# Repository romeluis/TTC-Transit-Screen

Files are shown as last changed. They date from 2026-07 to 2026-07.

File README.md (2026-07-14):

# TTC Transit Screen

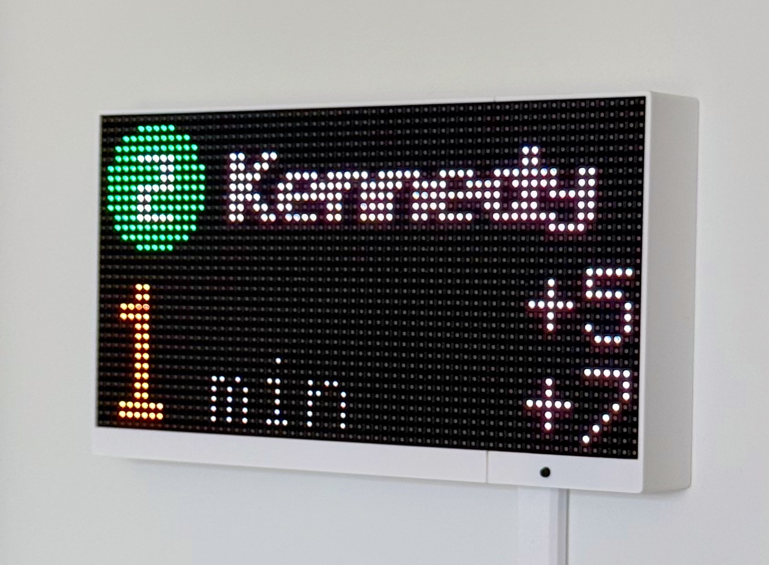
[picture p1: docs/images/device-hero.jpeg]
A wall-mounted TTC Transit Screen showing Line 2 arrivals


An open-source, Wi-Fi-connected TTC arrival display built around an ESP32-S3 and a 64×32 P4 HUB75 RGB LED panel. It shows the next arrivals for up to eight subway, streetcar, or bus stops, includes line-alert indicators, and is configured from a phone-friendly local web app.

This is an independent community project. It is not affiliated with, endorsed by, or supported by the Toronto Transit Commission. Transit data can be delayed, incomplete, or unavailable; do not rely on this display for safety-critical travel decisions.

## What it does

- Shows three upcoming arrivals on a bright 64×32 RGB matrix.
- Supports subway platforms through TTC NTAS and surface routes through the public NextBus/UMO feed.
- Shows a warning triangle when TTC's live-alert feed reports an active line issue.
- Stores up to eight pages and cycles through them with an optional button.
- Hosts a captive setup portal and a responsive local configuration page.
- Sleeps the panel and pauses feed polling on a configurable overnight schedule.
- Supports local over-the-air firmware updates.
- Requires no cloud account, application server, or hardcoded stop selection.

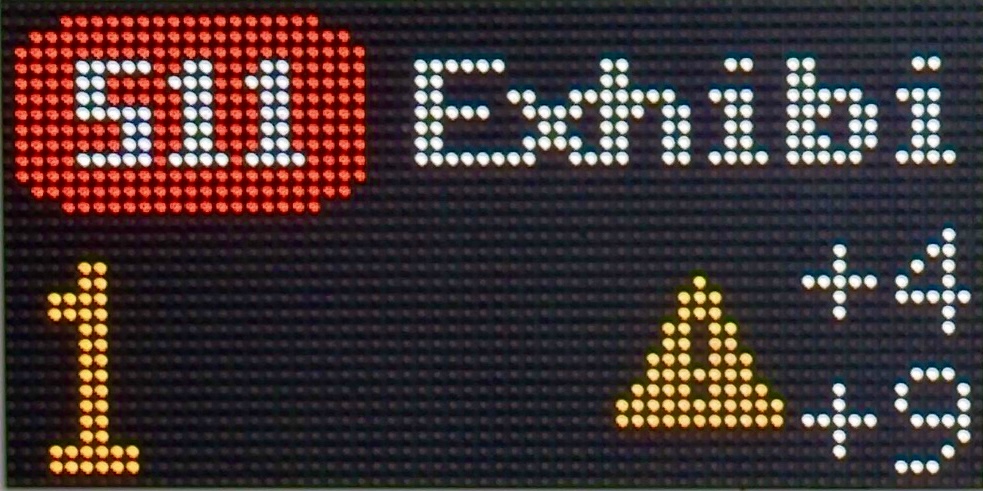
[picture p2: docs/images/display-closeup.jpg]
Close view of a surface-route arrival page


*The 64×32 layout showing a surface route, destination, alert state, and arrival minutes.*

## Supported boards

| PlatformIO environment | Memory | Status |
| --- | --- | --- |
| `esp32-s3-n16r8` | 16 MB flash, 8 MB octal PSRAM (`qio_opi`) | Default; tested on hardware |
| `esp32-s3-n8r2` | 8 MB flash, 2 MB quad PSRAM (`qio_qspi`) | Clean-build tested; not yet tested on hardware |

Both targets use the same 44-pin ESP32-S3 board layout, HUB75 wiring, firmware, and web app. Clone pin labels and power paths can vary, so compare your board with the wiring table before applying power.

## Bill of materials

| Qty | Item | Notes |
| ---: | --- | --- |
| 1 | [ESP32-S3 N16R8/N8R2 development board](https://www.aliexpress.com/item/1005006418608267.html) | N16R8 is the tested and default choice |
| 1 | [P4 indoor 64×32, 256×128 mm, 1/16-scan HUB75 panel](https://www.aliexpress.com/item/1005007439197222.html) | This geometry and scan rate are compile-time constants |
| 1 | Quality regulated 5 V / 3 A USB-C supply | Used by the tested USB-powered topology below |
| 1 | Low-resistance USB-C cable rated for at least 3 A | A marginal cable is a common source of resets and display corruption |
| 1 | HUB75 ribbon cable | Often included with the panel |
| 1 set | Female-to-female jumper wires or a purpose-built wiring harness | Keep signal wiring short and secure |
| 6 | M3×6 machine screws | Engage the panel's threaded inserts through the enclosure |
| 1 | [Momentary tact switch](https://www.aliexpress.com/item/1005007078720195.html) | Optional; the linked assortment is simply the kit used during development |
| 1 | Printed enclosure | Fusion archive and two printable STLs are included under [`hardware/enclosure`](hardware/enclosure/) |

A direct 5 V / 5 A supply, suitable wiring, and a fused distribution method are recommended as a fallback if the tested USB topology is unstable with your particular board or display.

## Power: read before wiring

The tested unit is powered through the ESP32's USB-C connector. The board's `5Vin` pin then supplies 5 V to the panel. At the fixed brightness value of 96, the measured normal workload was under 1 A because most pixels are black. That observation is not a worst-case rating: startup current, test patterns, different panels, USB cables, and board clones can draw more or expose a weak power path.

- Use a reputable regulated 5 V / 3 A USB-C supply and a short, low-resistance cable.
- Check the ESP32 board, connector, wiring, and panel for excess heat during initial testing.
- Watch for brownouts, spontaneous resets, flicker, or corrupted pixels.
- Do not feed external 5 V into `5Vin` while USB 5 V is also connected. Back-feeding can damage the board, computer, or supply.
- Never power the panel from the ESP32's 3.3 V pin or through its voltage regulator.

If USB power is not stable, use a regulated 5 V / 5 A supply split directly to the panel power input and the ESP32 `5Vin`, with all grounds common. Disconnect that external 5 V before connecting an ordinary powered USB cable for flashing.

## HUB75 wiring

The firmware uses one fixed pin map. The table follows the two columns of a standard HUB75 input connector; confirm the `IN` connector and key orientation on your panel.

| HUB75 signal | ESP32-S3 GPIO | HUB75 signal | ESP32-S3 GPIO |
| --- | ---: | --- | ---: |
| R1 | 4 | G1 | 1 |
| B1 | 5 | G2 | 2 |
| R2 | 6 | B (row address) | 42 |
| B2 | 7 | D | 41 |
| A | 15 | LAT / STB | 40 |
| C | 16 | E | GND |
| CLK | 17 | GND | GND |
| OE | 18 | GND | GND |

Connect every panel ground on the HUB75 header to ESP32 ground. Connect panel power `VCC` to the board's `5Vin` only when using the tested USB topology, and panel power ground to the same common ground. The 32-row, 1/16-scan panel does not use address line E, so E is tied to ground.

For the optional page/reset button, connect the momentary switch between GPIO21 and GPIO47. GPIO21 is the active-low input; GPIO47 is driven LOW as a virtual ground because of the compact harness layout. This virtual ground is only for the switch's tiny current—never connect a display, LED, or other load to GPIO47.

Without the button, the device still provisions, fetches data, sleeps on schedule, and can be managed through the web app. Only the first configured page is shown, and physical factory reset is unavailable.

## Prebuilt firmware

The [latest GitHub release](https://github.com/romeluis/TTC-Transit-Screen/releases/latest) includes ready-to-flash binaries for both supported memory variants. Choose the file whose board name exactly matches your ESP32-S3:

| File suffix | Use |
| --- | --- |
| `esp32-s3-n16r8-factory.bin` | First USB installation on the tested 16 MB flash / 8 MB PSRAM board |
| `esp32-s3-n16r8-ota.bin` | Firmware-tab update for the tested N16R8 board |
| `esp32-s3-n8r2-factory.bin` | First USB installation on the compile-supported 8 MB flash / 2 MB PSRAM board |
| `esp32-s3-n8r2-ota.bin` | Firmware-tab update for the compile-supported N8R2 board |

The `factory` images contain the bootloader, partition table, and application and are written at address `0x0`. Install [esptool](https://docs.espressif.com/projects/esptool/en/latest/esp32s3/installation.html), connect the board over USB, then run:

```sh
python -m esptool --chip esp32s3 --port /dev/your-port write-flash 0x0 ttc-transit-screen-v1.1.0-esp32-s3-n16r8-factory.bin
```

Replace the port and filename for your board. If the board does not enter download mode automatically, hold BOOT, tap RESET, start the command, then release BOOT. The release also includes `SHA256SUMS.txt` so downloads can be verified before flashing.

## Build and flash

Install [PlatformIO Core](https://docs.platformio.org/en/latest/core/installation/index.html), clone this repository, and run the commands from its root.

```sh
# Default, hardware-tested N16R8 target
pio run -e esp32-s3-n16r8
pio run -e esp32-s3-n16r8 -t upload

# Compile-supported N8R2 target
pio run -e esp32-s3-n8r2
pio run -e esp32-s3-n8r2 -t upload

# Optional serial diagnostics
pio device monitor -b 115200
```

The pre-build script compresses `web/index.html` and the station catalog into `include/web_page.h`; the generated header is intentionally ignored by Git. Use the native USB connector labelled `USB` when the board exposes both native USB and UART connectors. If automatic upload does not start, hold BOOT, tap RESET, begin the upload, then release BOOT.

### Fixed build-time settings

This project intentionally has no runtime brightness control. The tested value is `PANEL_BRIGHTNESS = 96` in [`src/config.h`](src/config.h). Change it at source level only, then rebuild and re-check current draw and temperature.

The following hardcoded values are intentional and collected here so they are easy to review before a build:

| Setting | Compiled value |
| --- | --- |
| Panel | 64×32 pixels, 1/16 scan; shared pins listed above |
| Brightness | 96 of 255 |
| Maximum pages | 8 |
| Arrival polling | 25 seconds per feed, staggered by 3 seconds |
| Alert polling | 120 seconds |
| Stale-data threshold | 90 seconds |
| HTTP timeout | 10 seconds |
| Wi-Fi connection timeout | 45 seconds |
| Reconnect backoff | 5–60 seconds |
| Portal fallback after lost Wi-Fi | 5 minutes |
| Stored-network retry while in portal | 2 minutes |
| Physical factory-reset hold | 10 seconds |
| Setup network | Open SSID `TTC-Setup` |
| Local hostname | `ttc` / `http://ttc.local` |
| Timezone | `America/Toronto` POSIX rules; NTP via `pool.ntp.org` and `time.google.com` |
| Default sleep schedule | 9 PM–6 AM local time; 30-second button wake |
| Subway feed | `https://ntas.ttc.ca/api/ntas/get-next-train-time/` |
| Surface feed | `https://retro.umoiq.com/service/publicJSONFeed` with agency `ttc` |
| Alert feed | `https://alerts.ttc.ca/api/alerts/live-alerts` |

Stops and the active sleep schedule are not hardcoded; they are stored in the device's NVS after configuration.

## First-time setup

1. Power the assembled device and wait for the `WiFi Setup` screen.
2. Join the open Wi-Fi network `TTC-Setup` from a phone or computer.
3. Open the captive-portal prompt. If it does not appear, browse to the IP shown on the panel.
4. Open the **WiFi** tab, scan or type the network name, enter its password, and choose **Save & connect**.
5. After restart, browse to [http://ttc.local](http://ttc.local). If mDNS is unavailable on your network, use the IP shown in the web app or serial log.
6. In **Stops**, add up to eight pages in the order you want them displayed, then choose **Save to device**.
7. In **Display**, keep the default overnight schedule or set your preferred local hours and button wake time.

Subway stops come from the embedded station/platform catalog. Streetcar and bus selectors are loaded through the ESP32's NextBus proxy and therefore require internet access. A fresh device contains no default stops or personal location data.

## Web app

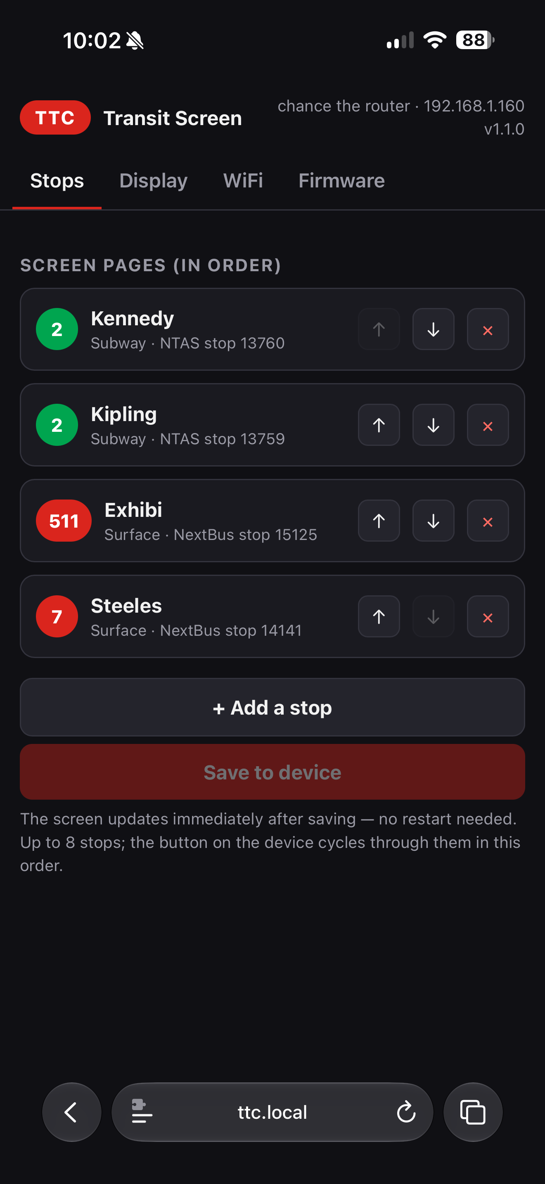
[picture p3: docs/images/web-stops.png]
Mobile Stops tab listing configured transit pages


*The Stops tab adds, removes, reorders, and saves up to eight display pages.*

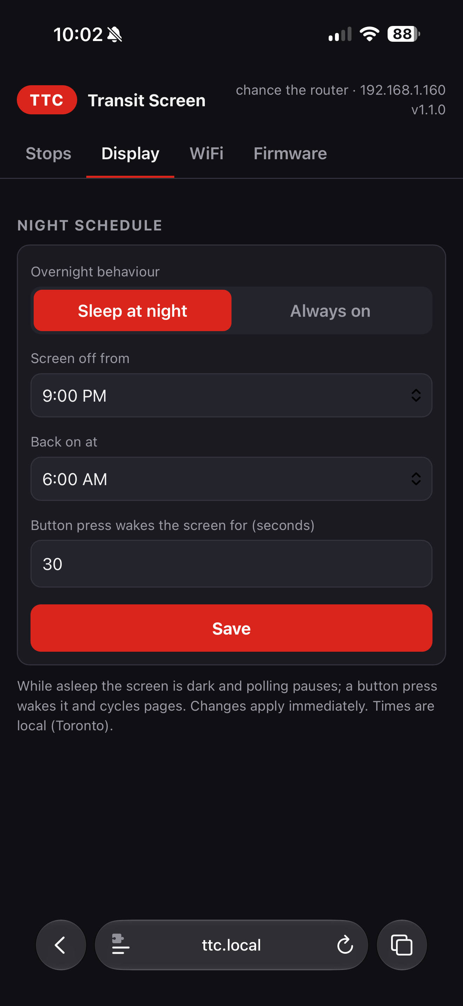
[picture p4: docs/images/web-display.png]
Mobile Display tab with overnight schedule settings


*The Display tab configures the panel's overnight sleep window and button wake time. It does not include brightness control.*

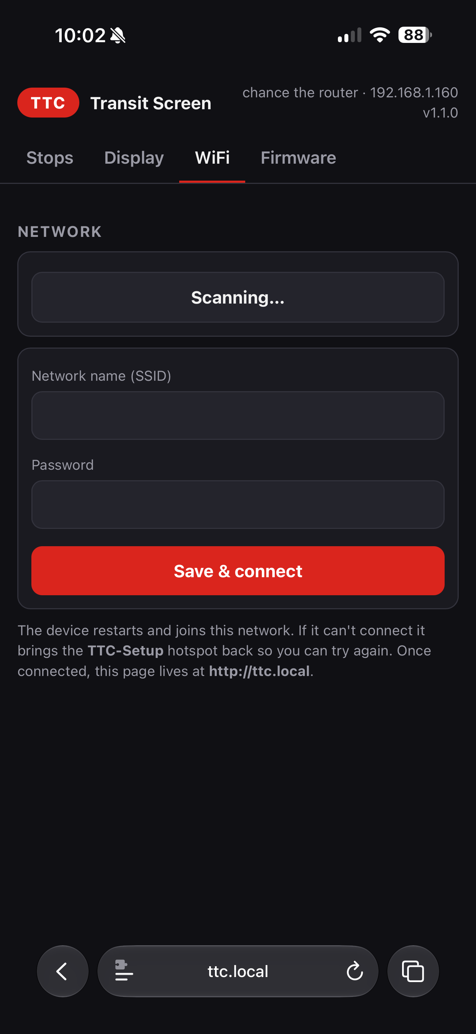
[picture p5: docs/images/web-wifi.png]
Mobile Wi-Fi tab with blank credential fields


*The Wi-Fi tab scans for a network, saves credentials, and reconnects the device.*

## Daily operation

- A short button press cycles pages in the configured order.
- During the sleep window, the first press wakes the panel without changing page. Further presses while awake cycle pages and extend the wake timer.
- Holding the button for 10 seconds after boot wipes Wi-Fi credentials, stops, and screen settings, then restarts the setup portal.
- If Wi-Fi drops, the firmware retries with exponential backoff. After a prolonged outage it reopens the setup portal while continuing to retry stored credentials.
- Feed polling pauses while the screen is asleep and resumes immediately on wake.

## Local firmware update

Build the firmware for the exact memory variant installed. In the web app's **Firmware** tab, upload:

- `.pio/build/esp32-s3-n16r8/firmware.bin`, or
- `.pio/build/esp32-s3-n8r2/firmware.bin`.

The ESP32 writes to the inactive OTA slot and restarts only after a successful upload. The firmware page is unauthenticated; read the security section before enabling this device on a shared network.

## Enclosure

The enclosure source and both printable halves are in [`hardware/enclosure`](hardware/enclosure/). The assembled STL bounds are approximately **260.5 × 142.5 × 36 mm**. The fit was tested in PLA. A reasonable starting profile is 0.2 mm layers, three walls, and 20% infill, with each half laid flat on its broad back face.

The enclosure has six panel mounting holes for M3×6 screws. It is provided as-is by a hobbyist designer: printer calibration, panel revisions, cable strain relief, and tolerances vary. Test-fit before final assembly, do not overtighten the panel inserts, and contributions improving the design are welcome.

## Architecture and repository layout

| Path | Purpose |
| --- | --- |
| `src/main.cpp` | Network state machine, scheduling, button handling, sleep/wake behavior |
| `src/transit_data.cpp` | TTC/NextBus fetching and JSON parsing |
| `src/display.cpp` | Shared 64×32 HUB75 rendering |
| `src/settings.cpp` | NVS-backed stops, Wi-Fi credentials, and screen schedule |
| `src/webconfig.cpp` | Captive portal, local HTTP API, feed proxy, reboot, and OTA |
| `web/` | Embedded responsive configuration UI and public station catalog |
| `tools/build_web.py` | Deterministic web-asset compression before each firmware build |
| `hardware/enclosure/` | Fusion archive, printable STLs, and print notes |

The device connects directly to public transit feeds, parses only the fields it needs, stores runtime configuration in NVS, renders the active page to the HUB75 panel, and serves the web app over the local network. No companion service is required.

### Data sources

- TTC NTAS next-train endpoint for subway platform estimates
- NextBus/UMO public JSON feed for bus and streetcar predictions
- TTC live-alert endpoint for line-level disruption indicators
- TTC GTFS-derived platform codes in the embedded station catalog

These are public endpoints, not stable contracts. Upstream schema, availability, stop codes, or access policies may change without notice.

## Security model

> **Trusted LAN only.** This firmware is designed for a private network, not an untrusted, guest, school, workplace, or internet-exposed network.

- The `TTC-Setup` access point is open and its captive portal has no authentication.
- Wi-Fi credentials are submitted over plaintext local HTTP and stored unencrypted in ESP32 NVS.
- The status endpoint and page expose the connected SSID and local IP address.
- Stop/schedule/Wi-Fi configuration, reboot, and OTA endpoints are unauthenticated.
- HTTPS certificate validation is disabled for the public transit feeds, so transit responses are not protected against an active network attacker.

Do not port-forward the device, expose it through a public reverse proxy, or place it on a network where untrusted clients can reach it. A separate trusted IoT VLAN is a good deployment choice. See [`SECURITY.md`](SECURITY.md) for the full disclosure and reporting guidance.

## Troubleshooting

| Symptom | Checks |
| --- | --- |
| Reboots, flicker, or random pixels | Use a better 5 V supply/cable, shorten power leads, tie all grounds together, and try the direct 5 V / 5 A split topology |
| Panel is blank | Confirm HUB75 `IN` orientation, OE/LAT/CLK wiring, common ground, panel power, and the 1/16-scan 64×32 panel type |
| Colours or rows are wrong | Recheck R/G/B and A/B/C/D wires; confirm E is grounded and that your panel is not a different scan geometry |
| `TTC-Setup` does not appear | Hold the optional button for 10 seconds after boot, or erase flash over USB and reflash |
| `ttc.local` does not resolve | Use the device IP from serial output or your router's client list; some networks do not pass mDNS |
| Streetcar/bus picker fails | Confirm internet access; the browser relies on the ESP32 proxy because the upstream feed has no browser CORS support |
| No or stale arrivals | Verify stop codes, upstream service status, Wi-Fi signal, and serial diagnostics; predictions are controlled by the external feeds |
| OTA rejects a file | Rebuild for the exact N16R8/N8R2 target and upload that environment's `firmware.bin` |

## Release verification

CI clean-builds both memory variants. Before distributing hardware, repeat the N16R8 smoke test: cold boot/display initialization, first-time provisioning, stop fetching, disconnect/reconnect, scheduled sleep and button wake, page cycling, 10-second factory reset, and OTA update. Treat N8R2 as compile-tested until the same checklist has been completed on physical N8R2 hardware.

## License

This repository—including firmware, web assets, documentation, photos, and enclosure files—is released under the [MIT License](LICENSE).

Created and maintained by [@romeluis](https://github.com/romeluis).

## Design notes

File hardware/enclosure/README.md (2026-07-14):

# P4 panel enclosure

This directory contains the editable Fusion archive and two printable halves for the 256×128 mm P4 HUB75 panel used by TTC Transit Screen.

- `p4-screen-case.f3d` — editable Fusion design archive
- `left-body.stl` — left enclosure half
- `right-body.stl` — right enclosure half

The combined STL bounds are approximately **260.5 × 142.5 × 36 mm**. The enclosure was test-printed in PLA. As a starting point, place each half flat on its broad back face and use:

- 0.2 mm layer height
- three walls/perimeters
- 20% infill
- supports only where your slicer's preview shows they are necessary

Use six M3×6 machine screws through the enclosure holes into the panel's threaded inserts. Start every screw loosely, align the panel, then tighten evenly. Do not overtighten the inserts.

This is a hobbyist design supplied as-is. Panel frames, connectors, print shrinkage, and printer calibration vary. Check cable clearance and test-fit all parts before final assembly. Improvements to tolerances, joining features, ventilation, or strain relief are welcome.

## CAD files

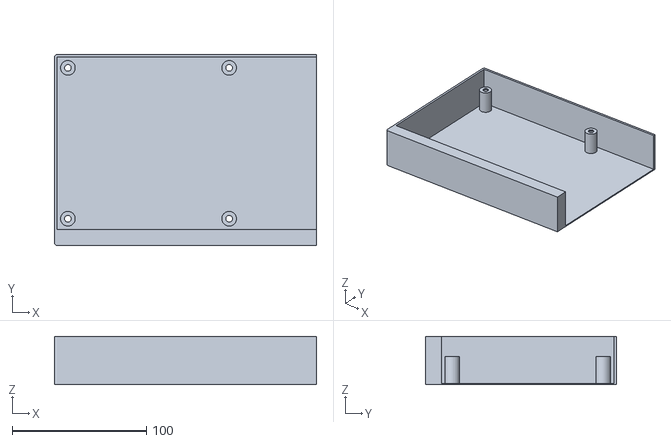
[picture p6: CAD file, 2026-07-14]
hardware/enclosure/left-body.stl
195.4 x 142.5 x 36.0

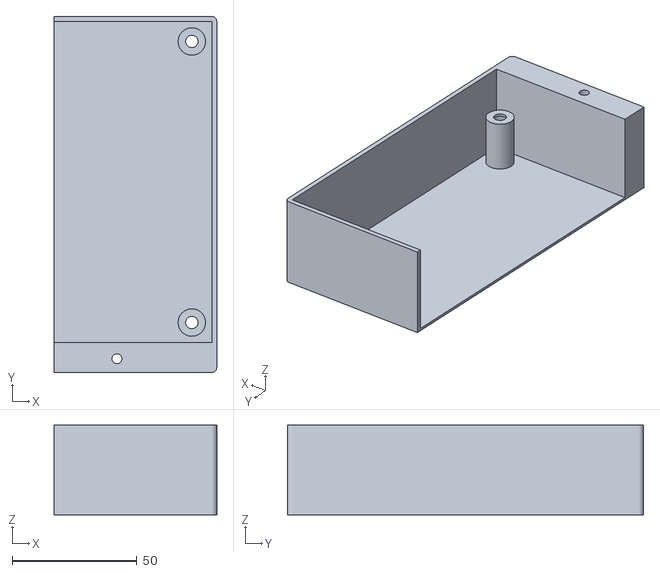
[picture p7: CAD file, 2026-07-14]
hardware/enclosure/right-body.stl
65.1 x 142.5 x 36.0

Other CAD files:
hardware/enclosure/p4-screen-case.f3d

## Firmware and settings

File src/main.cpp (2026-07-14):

// TTC Transit Screen — fetch-first firmware.
//
// Polls a prediction feed per configured stop (gStops, NVS-backed via the
// web-config UI: subway via NTAS, streetcar/bus via NextBus) and prints
// arrivals to serial. Rendering targets the HUB75 matrix with ENABLE_DISPLAY;
// without it the firmware remains usable for serial diagnostics.
//
// Networking is a small state machine: stored credentials are tried first
// (StaConnecting); if none exist or they keep failing, the device hosts an
// open setup AP with a captive portal (Portal) where WiFi and stops can be
// configured. The web server runs in every mode.

#include <Arduino.h>
#include <ESPmDNS.h>
#include <WiFi.h>
#include <esp_system.h> // esp_reset_reason
#include <time.h>

#include "config.h"
#include "display.h"
#include "settings.h"
#include "transit_data.h"
#include "webconfig.h"

static TransitState state;
static AlertState alerts;
static uint32_t feedDueAtMs[MAX_STOPS];
static uint32_t alertsDueAtMs = 0; // set in scheduleFetches (count is runtime)

enum class NetMode : uint8_t { StaConnecting, StaConnected, Portal };
static NetMode netMode = NetMode::Portal;
static String staSsid, staPass;               // from NVS
static uint32_t staDeadlineMs = 0;            // StaConnecting -> portal at
static uint32_t staRetryAtMs = 0;             // next reconnect attempt
static uint32_t staBackoffMs = WIFI_RETRY_BASE_MS;
static uint32_t staLostSinceMs = 0;           // 0 = link is up
static uint32_t statusScreenAtMs = 0;         // boot/setup screen refresh
static bool timeConfigured = false;

static FetchStatus fetchStop(const StopConfig &stop, Departures &dep) {
  return stop.kind == RouteKind::Subway
             ? fetchSubway(stop.stopId, dep)
             : fetchNextBus(stop.route, stop.stopId, dep);
}

// (Re)arm the per-stop fetch timers, staggered so requests don't burst;
// alerts go last. startInMs delays the whole train (e.g. past the IP splash).
static void scheduleFetches(uint32_t startInMs) {
  uint32_t now = millis();
  for (size_t i = 0; i < gStopCount; i++) {
    feedDueAtMs[i] = now + startInMs + i * FEED_STAGGER_MS;
  }
  alertsDueAtMs = now + startInMs + gStopCount * FEED_STAGGER_MS;
}

#if HAS_SCREEN
static uint8_t activePage = 0;
static bool displayOk = false;
static bool screenOn = true;
static uint32_t nightWakeUntilMs = 0; // button-wake deadline inside the window

// Current transit page — or the pointer to the config UI when the stop list
// is empty (fresh device, or everything deleted in the web UI).
static void renderCurrent() {
  if (!displayOk) {
    return;
  }
  if (gStopCount == 0) {
    displayShowInfo("No stops", "add at", MDNS_HOSTNAME ".local");
    return;
  }
  displayRender(state, alerts, activePage);
}

// True while local time is inside the configured screen-off window (gScreen,
// web-editable). Before the first NTP sync the clock reads as 1970, which
// fails the sanity check and keeps the screen on.
static bool inScreenOffWindow() {
  if (!gScreen.sleepEnabled || gScreen.offHour == gScreen.onHour) {
    return false;
  }
  time_t nowT = time(nullptr);
  if (nowT < 1609459200) { // 2021-01-01; clock not synced yet
    return false;
  }
  struct tm t;
  localtime_r(&nowT, &t);
  int h = t.tm_hour;
  if (gScreen.offHour < gScreen.onHour) {
    return h >= gScreen.offHour && h < gScreen.onHour;
  }
  return h >= gScreen.offHour || h < gScreen.onHour;
}

// Turn the screen on/off as the window and button-wake deadline dictate.
static void updateScreenPower() {
  bool wantOn = !inScreenOffWindow() ||
                (int32_t)(millis() - nightWakeUntilMs) < 0;
  if (wantOn != screenOn) {
    screenOn = wantOn;
    Serial.printf("[screen] %s\r\n", wantOn ? "on" : "off (night window)");
    displaySetPower(wantOn);
    if (wantOn) {
      renderCurrent();
    }
  }
}

// Page-toggle button, active low. During the night window the first press
// wakes the screen for gScreen.wakeSecs; presses while awake cycle pages
// and extend the wake deadline. Holding the
// button FACTORY_RESET_HOLD_MS wipes the config (WiFi + stops) and reboots
// into the setup portal.
static void pollPageButton() {
  static bool lastPressed = false;
  static uint32_t lastChangeMs = 0;
  static uint32_t pressedAtMs = 0;
  bool pressed = digitalRead(PAGE_BUTTON_PIN) == LOW;
  if (pressed != lastPressed && millis() - lastChangeMs > 50) {
    lastChangeMs = millis();
    lastPressed = pressed;
    if (pressed) {
      pressedAtMs = millis();
      if (inScreenOffWindow()) {
        nightWakeUntilMs = millis() + gScreen.wakeSecs * 1000UL;
      }
      if (!screenOn) {
        updateScreenPower(); // waking press: turn on, don't cycle
        return;
      }
      // Cycle through the configured stops in list order.
      if (gStopCount > 0) {
        activePage = (uint8_t)((activePage + 1) % gStopCount);
        renderCurrent();
      }
    }
  }
  if (lastPressed && millis() - pressedAtMs > FACTORY_RESET_HOLD_MS) {
    displayShowWarning("Reset", "all config");
    delay(1500); // let the message register before the reboot blanks it
    settingsFactoryReset();
  }
}
#endif

// ---- WiFi state machine -------------------------------------------------------

static void startSta() {
  Serial.printf("[WiFi] connecting to \"%s\"\r\n", staSsid.c_str());
  WiFi.mode(WIFI_STA);
  WiFi.setHostname(MDNS_HOSTNAME);
  WiFi.begin(staSsid.c_str(), staPass.c_str());
  netMode = NetMode::StaConnecting;
  staDeadlineMs = millis() + STA_CONNECT_TIMEOUT_MS;
}

static void startPortal() {
  webconfigStartPortal();
  netMode = NetMode::Portal;
  staRetryAtMs = millis() + PORTAL_STA_RETRY_MS;
  statusScreenAtMs = 0; // draw the setup screen immediately
#if HAS_SCREEN
  // The portal can start inside the night window (WiFi died while asleep);
  // the setup instructions must be visible regardless.
  screenOn = true;
  displaySetPower(true);
#endif
}

static void onStaConnected() {
  netMode = NetMode::StaConnected;
  staLostSinceMs = 0;
  staBackoffMs = WIFI_RETRY_BASE_MS;
  String ip = WiFi.localIP().toString();
  Serial.printf("[WiFi] connected, IP %s, RSSI %d dBm\r\n", ip.c_str(),
                WiFi.RSSI());

  if (!timeConfigured) {
    configTzTime(TZ_INFO, NTP_SERVER_1, NTP_SERVER_2); // for the night window
    timeConfigured = true;
  }
  MDNS.end();
  if (MDNS.begin(MDNS_HOSTNAME)) {
    MDNS.addService("http", "tcp", 80);
    Serial.println("[mDNS] http://" MDNS_HOSTNAME ".local/");
  }

#if HAS_SCREEN
  // Straight to the transit pages (first fetch fills them within seconds);
  // a fresh device with no stops shows the pointer to the config UI instead.
  renderCurrent();
#endif
  scheduleFetches(0);
}

// Persist + hot-apply a new stop list from the web UI. Runs on the main
// thread (synchronous server), so no fetch is mid-flight while state resets.
static bool applyStops(const StopConfig *stops, size_t count) {
  if (!settingsSaveStops(stops, count)) {
    return false;
  }
  state = TransitState{};
  alerts = AlertState{};
  scheduleFetches(0);
#if HAS_SCREEN
  activePage = 0;
  renderCurrent();
#endif
  return true;
}

static void printFeedResult(const StopConfig &stop, const Departures &dep,
                            FetchStatus status, uint32_t elapsedMs) {
  Serial.printf("[up %6lus] %4s %-10s: ", millis() / 1000, stop.route,
                stop.dest);
  if (status == FetchStatus::Ok) {
    for (int i = 0; i < 3 && dep.next[i] >= 0; i++) {
      Serial.printf(i > 0 ? ", %d" : "%d", dep.next[i]);
    }
    Serial.print(" min");
  } else {
    Serial.print(fetchStatusName(status));
  }
  Serial.printf("  (%s, %lums)\r\n", fetchStatusName(status), elapsedMs);
}

void setup() {
  Serial.begin(115200);
  // Native USB CDC needs a moment for the host to attach.
  uint32_t t0 = millis();
  while (!Serial && millis() - t0 < 3000) {
    delay(10);
  }
  Serial.println();
  Serial.println("=== TTC Transit Screen " FW_VERSION " ===");

  settingsBegin(); // loads gStops from NVS

#if HAS_SCREEN
#ifdef PAGE_BUTTON_GND_PIN
  // Virtual ground for the page button (see config.h).
  pinMode(PAGE_BUTTON_GND_PIN, OUTPUT);
  digitalWrite(PAGE_BUTTON_GND_PIN, LOW);
#endif
  pinMode(PAGE_BUTTON_PIN, INPUT_PULLUP);
  // Cold power-up can catch the 5V rail mid-rise (panel PSU inrush) and the
  // DMA init fails where a warm reset succeeds. Retry, then reboot once —
  // the same cure as pressing RESET, which matters inside a closed
  // enclosure. The reset-reason guard prevents a reboot loop when the panel
  // genuinely isn't there.
  for (int attempt = 0; attempt < 3 && !displayOk; attempt++) {
    if (attempt > 0) {
      delay(300);
    }
    displayOk = displayInit();
  }
  Serial.printf("[display] init %s\r\n", displayOk ? "ok" : "FAILED");
  if (!displayOk && esp_reset_reason() != ESP_RST_SW) {
    Serial.println("[display] rebooting once to retry init on stable power");
    delay(250);
    ESP.restart();
  }
  displayShowBoot("starting");
#endif

  if (settingsGetWifi(staSsid, staPass)) {
    startSta();
  } else {
    Serial.println("[WiFi] no stored credentials, starting setup portal");
    startPortal();
  }
  webconfigBegin(applyStops);
}

void loop() {
  // HTTP + portal DNS + deferred restarts, in every mode — including while
  // the screen sleeps at night.
  webconfigTick();

  uint32_t now = millis();
  switch (netMode) {
  case NetMode::StaConnecting:
    if (WiFi.status() == WL_CONNECTED) {
      onStaConnected();
      break;
    }
    if ((int32_t)(now - staDeadlineMs) >= 0) {
      Serial.println("[WiFi] connect timed out, starting setup portal");
      startPortal();
      break;
    }
#if HAS_SCREEN
    if (now - statusScreenAtMs > 350) { // tick the loading animation
      statusScreenAtMs = now;
      displayShowBoot("connecting");
    }
#endif
    break;

  case NetMode::StaConnected:
    if (WiFi.status() != WL_CONNECTED) {
      if (staLostSinceMs == 0) {
        staLostSinceMs = now;
        staRetryAtMs = now; // first retry immediately
        staBackoffMs = WIFI_RETRY_BASE_MS;
        Serial.println("[WiFi] connection lost");
#if HAS_SCREEN
        displayShowWarning("No WiFi", staSsid.c_str());
#endif
      }
      if (now - staLostSinceMs > STA_LOST_PORTAL_AFTER_MS) {
        Serial.println("[WiFi] down too long, starting setup portal");
        startPortal();
        break;
      }
      if ((int32_t)(now - staRetryAtMs) >= 0) {
        Serial.printf("[WiFi] reconnecting (next retry in %lus)\r\n",
                      staBackoffMs / 1000);
        WiFi.disconnect();
        WiFi.begin(staSsid.c_str(), staPass.c_str());
        staRetryAtMs = now + staBackoffMs;
        staBackoffMs = min(staBackoffMs * 2, (uint32_t)WIFI_RETRY_MAX_MS);
      }
    } else if (staLostSinceMs != 0) {
      staLostSinceMs = 0;
      staBackoffMs = WIFI_RETRY_BASE_MS;
      Serial.printf("[WiFi] reconnected, IP %s\r\n",
                    WiFi.localIP().toString().c_str());
#if HAS_SCREEN
      renderCurrent();
#endif
    }
    break;

  case NetMode::Portal:
    // The background STA retry (below) may have gotten us online; if so the
    // setup AP has done its job.
    if (WiFi.status() == WL_CONNECTED) {
      Serial.println("[WiFi] configured network reachable again, closing portal");
      webconfigStopPortal();
      onStaConnected();
      break;
    }
    if (!staSsid.isEmpty() && (int32_t)(now - staRetryAtMs) >= 0) {
      Serial.println("[WiFi] portal: retrying stored credentials");
      WiFi.begin(staSsid.c_str(), staPass.c_str());
      staRetryAtMs = now + PORTAL_STA_RETRY_MS;
    }
#if HAS_SCREEN
    if (now - statusScreenAtMs > 1000) { // static screen; cheap to refresh
      statusScreenAtMs = now;
      displayShowInfo("WiFi Setup", AP_SSID,
                      WiFi.softAPIP().toString().c_str());
    }
#endif
    break;
  }

  if (netMode != NetMode::StaConnected || staLostSinceMs != 0) {
    delay(10);
    return; // status screens own the display; nothing to fetch yet
  }

#if HAS_SCREEN
  updateScreenPower();
  pollPageButton();
  // While the screen sleeps, stop polling too; the stale due times make all
  // feeds refresh immediately on wake. (webconfigTick already ran above.)
  if (!screenOn) {
    delay(10);
    return;
  }
#endif

  now = millis();
  for (size_t i = 0; i < gStopCount; i++) {
    if ((int32_t)(now - feedDueAtMs[i]) >= 0) {
      uint32_t startMs = millis();
      FetchStatus status = fetchStop(gStops[i], state.deps[i]);
      printFeedResult(gStops[i], state.deps[i], status, millis() - startMs);
      feedDueAtMs[i] = now + POLL_INTERVAL_MS;

#if HAS_SCREEN
      renderCurrent();
#endif
    }
  }

  if (gStopCount > 0 && (int32_t)(now - alertsDueAtMs) >= 0) {
    uint32_t startMs = millis();
    FetchStatus status = fetchAlerts(gStops, gStopCount, alerts);
    Serial.printf("[up %6lus] Alerts: ", millis() / 1000);
    for (size_t i = 0; i < gStopCount; i++) {
      Serial.printf(i > 0 ? ", %s %s" : "%s %s", gStops[i].route,
                    alerts.alert[i] ? "ALERT" : "ok");
    }
    Serial.printf("  (%s, %lums)\r\n", fetchStatusName(status),
                  millis() - startMs);
    alertsDueAtMs = now + ALERT_POLL_INTERVAL_MS;
#if HAS_SCREEN
    renderCurrent();
#endif
  }

  delay(10);
}

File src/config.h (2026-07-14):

// Central configuration: endpoints, timing, display geometry, and wiring.
#pragma once

#include <stdint.h>

// Shown in the web UI; bump before an OTA build so the update is verifiable.
#define FW_VERSION "1.1.0"

// ---- TTC data sources -------------------------------------------------------

// Subway NTAS API: https://ntas.ttc.ca/api/ntas/get-next-train-time/{stopCode}
#define NTAS_BASE_URL "https://ntas.ttc.ca/api/ntas/get-next-train-time/"

// NextBus/UMO public feed; route and stop tag are appended per configured stop.
#define NEXTBUS_BASE_URL                                                       \
  "https://retro.umoiq.com/service/publicJSONFeed"                            \
  "?command=predictions&a=ttc"

// ---- Stops shown on the screen -----------------------------------------------
// One page per entry, cycled by the button in list order. The route number
// picks the header glyph (subway disc / surface pill) and its TTC colors, and
// is matched against the live-alerts feed.
//
// The live list is gStops/gStopCount (settings.h), loaded from NVS. Nothing
// is hardcoded: a device with no saved config shows the "No stops" pointer
// until stops are added in the web UI.

enum class RouteKind : uint8_t {
  Subway, // NTAS; stopId is a platform-level stop code from TTC GTFS stops.txt
  Surface // NextBus (streetcar & bus); stopId is a NextBus stop tag
};

#define ROUTE_MAX_LEN 7 // route string, e.g. "511"
#define DEST_MAX_LEN 15 // header label; ~7 chars fits beside a 3-digit pill

struct StopConfig {
  RouteKind kind;
  char route[ROUTE_MAX_LEN + 1]; // "2", "511", "7", ...
  int stopId;
  char dest[DEST_MAX_LEN + 1];
};

// MAX_STOPS sizes the runtime state arrays.
#define MAX_STOPS 8

// Live service alerts (warning indicator for active line issues).
// ~100KB payload; fetched with a streaming filter, so poll sparingly.
#define ALERTS_URL "https://alerts.ttc.ca/api/alerts/live-alerts"
#define ALERT_POLL_INTERVAL_MS 120000UL

#define HTTP_USER_AGENT "ttc-transit-screen/1.0 (esp32-s3)"
#define HTTP_TIMEOUT_MS 10000

// ---- Timing ----------------------------------------------------------------

#define POLL_INTERVAL_MS 25000UL  // per feed
#define FEED_STAGGER_MS 3000UL    // offset between the three feeds
#define STALE_AFTER_MS 90000UL    // dim/flag data older than this
#define WIFI_RETRY_BASE_MS 5000UL // reconnect backoff start (doubles, caps at 60s)
#define WIFI_RETRY_MAX_MS 60000UL

// ---- WiFi provisioning & web config ------------------------------------------

// Open setup network hosted while unprovisioned. Must fit the 64px screen
// (10 chars max) so the setup instructions can show it.
#define AP_SSID "TTC-Setup"
#define MDNS_HOSTNAME "ttc" // http://ttc.local/
// Give stored credentials this long before falling back to the setup AP.
#define STA_CONNECT_TIMEOUT_MS 45000UL
// In portal mode with stored credentials, retry the configured network this often.
#define PORTAL_STA_RETRY_MS 120000UL
// A connection that stays down this long also falls back to the portal.
#define STA_LOST_PORTAL_AFTER_MS 300000UL
// Hold the page button this long (any time after boot) to wipe WiFi + stop
// config. Can't be a hold-through-power-on gesture: GPIO0 low at reset straps
// the chip into the ROM bootloader before the firmware ever runs.
#define FACTORY_RESET_HOLD_MS 10000UL

// ---- Clock & night dimming ---------------------------------------------------

#define TZ_INFO "EST5EDT,M3.2.0,M11.1.0" // America/Toronto
#define NTP_SERVER_1 "pool.ntp.org"
#define NTP_SERVER_2 "time.google.com"

// Defaults for the screen-sleep schedule (the live values are NVS-backed —
// gScreen in settings.h — and edited in the web UI's Display tab). The
// screen and polling sleep between these local hours; a button press wakes
// the screen for the configured number of seconds.
#define SCREEN_OFF_START_HOUR 21 // 9 PM
#define SCREEN_OFF_END_HOUR 6    // 6 AM
#define NIGHT_WAKE_SECS 30

// ---- Display (HUB75, only used when ENABLE_DISPLAY is defined) --------------

// 64x32 1/16-scan panel; E address line unused (tie to GND).
#define PANEL_WIDTH 64
#define PANEL_HEIGHT 32
#define PANEL_BRIGHTNESS 96 // 0-255, comfortable indoor level

// Library-default signal timing works with all ground pins tied together.
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
